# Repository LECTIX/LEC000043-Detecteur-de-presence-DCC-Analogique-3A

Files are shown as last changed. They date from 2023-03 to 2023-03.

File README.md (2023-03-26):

# LEC000043-Detecteur-de-presence-DCC-Analogique-3A
Fichiers sources pour le produit LEC000043

## Description du produit

### DCC (Digital)

En DCC, le détecteur d’occupation LEC000043 permet de détecter l’occupation d’un tronçon de voie et de déclencher de nombreux automatismes ou systèmes.
- Détecte tous les trains dans les **2 sens de marche**.
- Seuil de détection **réglable entre 1 et 10 mA**.
- **Courant max supporté** de 3A.
- Temporisation à la désactivation pour **éviter des réactivations intempestives**.
- **Possibilité de forcer** l'activation du relais via un bornier dédié.

### Analogique

Bien que ce module fonctionne en analogique de manière similaire au [LEC000042](https://github.com/LECTIX/LEC000042-Detecteur-de-presence-DCC-Analogique-1A), nous vous conseillons plutôt d'utiliser la version 1A pour une utilisation en analogique.

## Utiliser les fichiers sources pour fabriquer le produit

Il n'est **pas nécessaire de savoir souder ou d'être bon en électronique** pour se procurer ce produit. Grâce aux fichiers sources publiés ici, vous pouvez être en mesure de faire fabriquer ce produit par un sous traitant.

### Faire fabriquer chez un sous traitant

Il est aujourd'hui possible de faire fabriquer à moindre cout des cartes électroniques. Nous recommendons [JLCPCB](https://jlcpcb.com/) si vous voulez aller au moins cher. Si vous préférez un acteur européen, [eurocircuits](https://www.eurocircuits.com/) est un des acteurs reconnus.

IMAGE ALT TEXT (http://www.youtube.com/watch?v=RXGGvsUtz0c "TUTO : faire fabriquer un produit LECTIX")

1. Télécherger les sources de ce produit en cliquant sur le bouton `Code`, puis `Download ZIP`.
1. Décompresser le dossier.
1. Les fichiers pour la fabrication se trouvent dans le répertoire `hardware/prod`.
1. Se connecter sur [https://cart.jlcpcb.com/quote](https://cart.jlcpcb.com/quote)
1. Cliquer sur le bouton `Add gerber file` et sélectionner le fichier `gerbers.zip`.
1. Sélectionnez la quantité de cartes que vous souhaitez dans le champs `PCB Qty`.
1. Laisser toutes les autres options par défaut, puis cliquez sur le toggle switch en face de `PCB Assembly`, et enfin sur le bouton `confirm`.
1. Une preview de la carte électronique sans les composants doit apparaitre. Cliquez sur `NEXT`.
1. Cliquez sur le bouton `Add BOM File`, puis sélectionnez le fichier `bom.csv`
1. Cliquez sur le bouton `Add CPL File`, puis sélectionnez le fichier `pos.csv`
1. **Vérifier que tous les composants sont en stock** et bien sélectionnés, puis cliquez sur `NEXT`.
1. Une preview de la carte avec ses composants apparait. Continuer le chemin en cliquant sur `NEXT`.
1. Le prix final apparait. Sélectionnez la catégorie du produit, puis cliquez sur `SAVE TO CART`.
1. Une fois sauvegardé dans votre panier, vous pouvez valider votre commande et choisir le moyen d'acheminement. Afin de ne pas avoir à se préoccuper des frais de douane, nous vous conseillons de choisir une méthode d'expédition DDP.

Vous receverez vos cartes sous 1 à 3 semaines. 

**Nous ne sommes en aucun cas responsables des cartes qui arriveraient défectueuses ou non fonctionnelles.**

### Modifications des fichiers sources

Installez kicad 6 (ou version supérieure), et ouvrez le fichier LEC000043.kicad_pro

### Regénérer les fichiers gerber, BOM, et position (Optionnel)

Peut se faire simplement en utilisant kikit :

```
cd hardware
docker run --rm -w /kikit -v $PWD:/kikit yaqwsx/kikit kikit fab jlcpcb --assembly --no-drc --schematic LEC000043.kicad_sch --field LCSC --corrections JLCPCB_CORRECTION --nametemplate LEC000043_{} LEC000043.kicad_pcb prod/

```
## Notices

### DCC

[Manuel FR](docs/dcc/manual_fr.pdf)

[Manuel EN](docs/dcc/manual_en.pdf)

### Analogique

Se référer au produit [LEC000042](https://github.com/LECTIX/LEC000042-Detecteur-de-presence-DCC-Analogique-1A).

## License
Tous nos fichiers sont plubliés sous la license CERN Open Hardware Licence Version 2 - Strongly Reciprocal

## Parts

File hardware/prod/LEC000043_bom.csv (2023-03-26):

Comment | Designator | Footprint | LCSC
100uF | C1,C3 | 0_capacitors:CP_Elec_6.3x5.8 | C249982
100nF | C2,C5 | Capacitor_SMD:C_0603_1608Metric | C14663
10n | C6 | Capacitor_SMD:C_0603_1608Metric | C57112
10uF | C7,C8 | Capacitor_Tantalum_SMD:CP_EIA-3216-18_Kemet-A | C7171
MB10S | D1 | Package_TO_SOT_SMD:TO-269AA | C2488
1N4148WS | D2,D9,D10 | Diode_SMD:D_SOD-323 | C2128
RS3M | D3,D4,D5,D8 | Diode_SMD:D_SMC | C330389
D_Schottky_Small | D6 | Diode_SMD:D_SMA | C22452
LED | D7 | LED_SMD:LED_0603_1608Metric | C72043
FORCE_ACTIVATION | J1 | 0_connectors:TerminalBlock_bornier-2_P5.08mm-blue | C430621
TRACKS_OUT | J2 | 0_connectors:TerminalBlock_bornier-2_P5.08mm-blue | C430621
TRACKS_IN | J3 | 0_connectors:TerminalBlock_bornier-2_P5.08mm-green | C395849
CONTACT_1 | J5 | 0_connectors:TerminalBlock_bornier-3_P5.08mm-blue | C430620
CONTACT_2 | J6 | 0_connectors:TerminalBlock_bornier-3_P5.08mm-blue | C430620
HK19F-5V | K1 | 0_relays:Relay_DPDT_HK19F | C54512
47uH | L1 | Inductor_SMD:L_12x12mm_H6mm | C169398
S8050 | Q1 | Package_TO_SOT_SMD:SOT-23 | C2146
27 | R1 | Resistor_SMD:R_0603_1608Metric | C25190
3k | R2 | Resistor_SMD:R_0603_1608Metric | C4211
1k | R3,R5,R6 | Resistor_SMD:R_0603_1608Metric | C21190
180k | R4 | Resistor_SMD:R_0603_1608Metric | C22827
10k | R7 | Resistor_SMD:R_0603_1608Metric | C25804
500k | RV1 | 0_potentiometers:BOURNS-3362P_pot | C125021
NE555 | U1 | Package_SO:SOIC-8_3.9x4.9mm_P1.27mm | C7593
CYPC817 | U2 | Package_DIP:SMDIP-4_W9.53mm_Clearance8mm | C385060
XL1509-ADJE1 | U3 | Package_SO:SOP-8_3.76x4.96mm_P1.27mm | C74192

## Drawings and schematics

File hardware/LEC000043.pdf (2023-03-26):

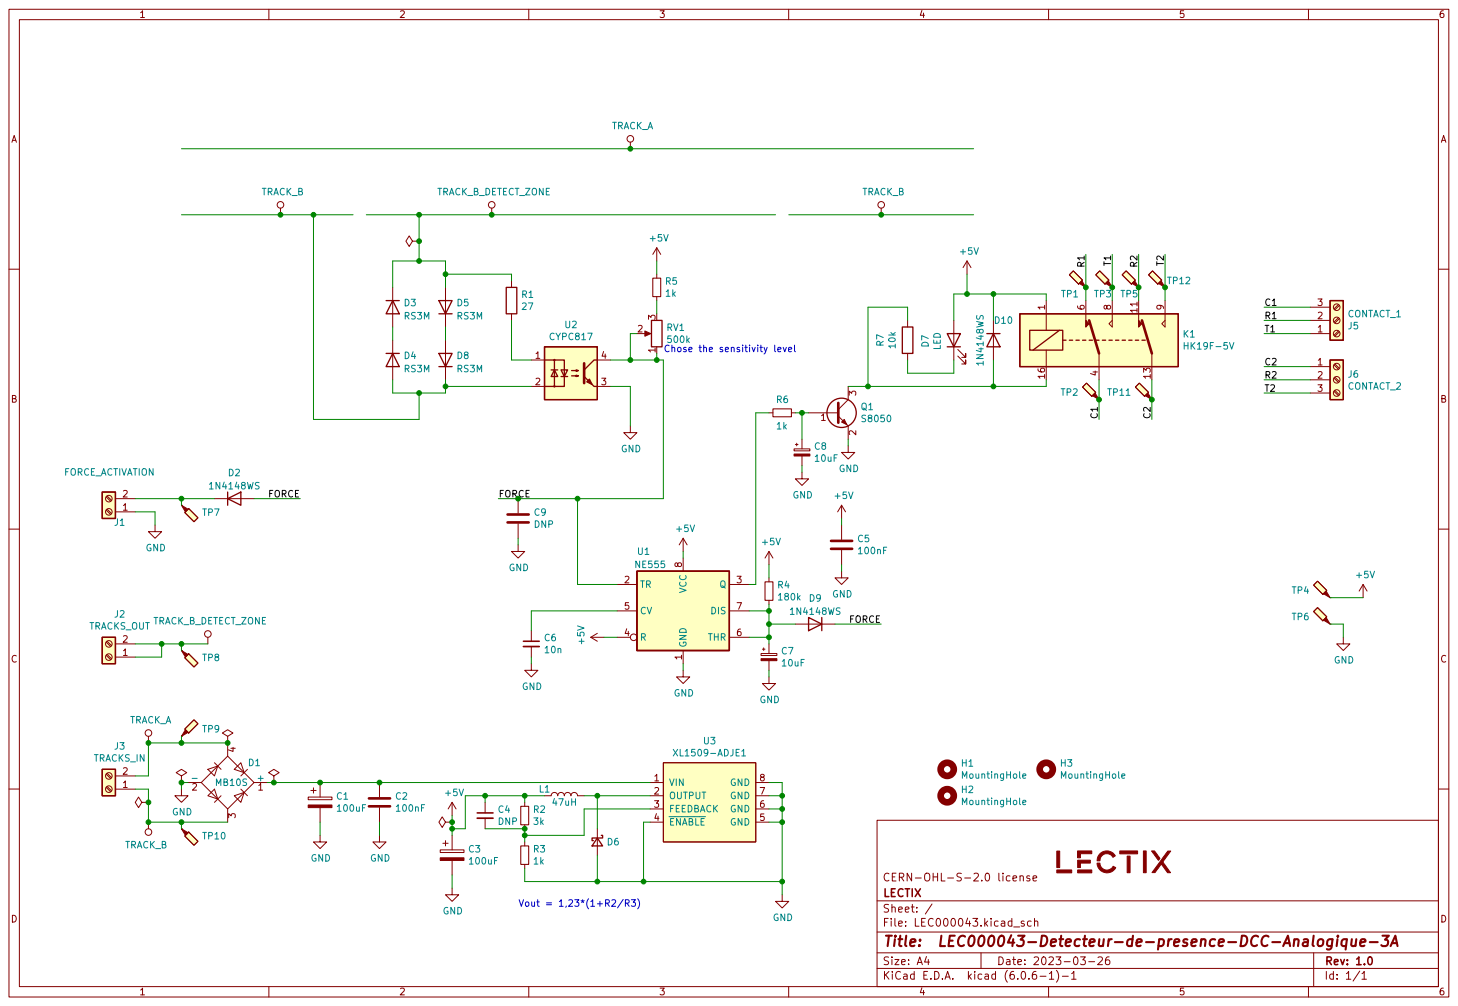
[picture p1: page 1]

File: LEC000043.kicad_sch Sheet: / LECTIX CERN-OHL-S-2.0 license

Id: 1/1 Title: LEC000043-Detecteur-de-presence-DCC-Analogique-3A

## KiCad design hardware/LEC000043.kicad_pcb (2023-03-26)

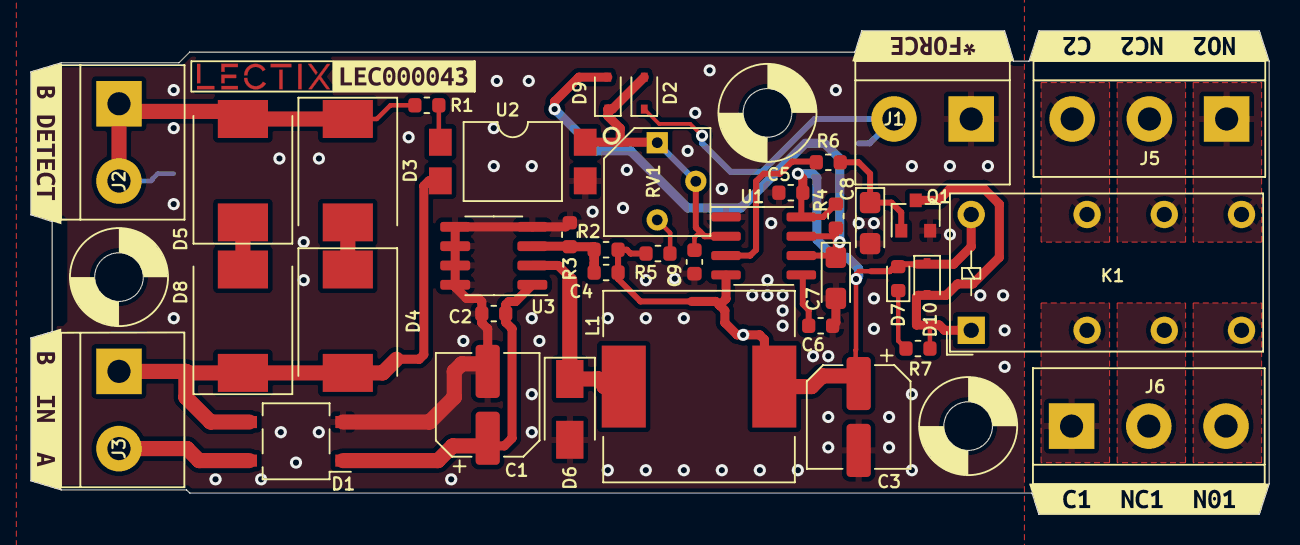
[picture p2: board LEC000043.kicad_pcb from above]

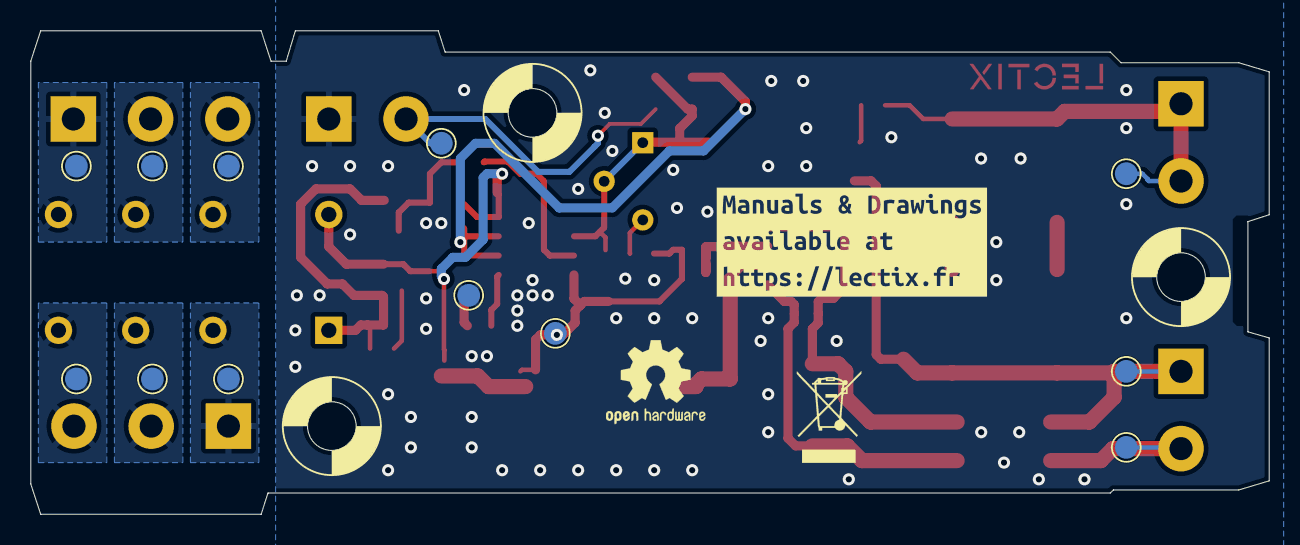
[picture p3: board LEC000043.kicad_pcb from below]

Board: 2 copper layers, 81.4 x 31.8 mm, 61 parts (13 on the bottom side), 26 nets.

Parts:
C1, C3: 100uF; CP_Elec_6.3x5.8
C2, C5: 100nF; C_0603_1608Metric
C4, C9: DNP; C_0603_1608Metric
C6: 10n; C_0603_1608Metric
C7, C8: 10uF; CP_EIA-3216-18_Kemet-A
D1: MB10S; TO-269AA
D2, D9, D10: 1N4148WS; D_SOD-323
D3, D4, D5, D8: RS3M; D_SMC
D6: D_Schottky_Small; D_SMA
D7: LED; LED_0603_1608Metric
H1, H2, H3: MountingHole; MountingHole_3.2mm_M3
J1: FORCE_ACTIVATION; TerminalBlock_bornier-2_P5.08mm-blue
J2: TRACKS_OUT; TerminalBlock_bornier-2_P5.08mm-blue
J3: TRACKS_IN; TerminalBlock_bornier-2_P5.08mm-green
J5: CONTACT_1; TerminalBlock_bornier-3_P5.08mm-blue
J6: CONTACT_2; TerminalBlock_bornier-3_P5.08mm-blue
K1: HK19F-5V; Relay_DPDT_HK19F
L1: 47uH; L_12x12mm_H6mm
LOGO1: logo_lectix_25mm; Logo_10mm
Q1: S8050; SOT-23
R1: 27; R_0603_1608Metric
R2: 3k; R_0603_1608Metric
R3, R5, R6: 1k; R_0603_1608Metric
R4: 180k; R_0603_1608Metric
R7: 10k; R_0603_1608Metric
RV1: 500k; BOURNS-3362P_pot
TP1, TP2, TP3, TP4, TP5, TP6, TP7, TP8, TP9, TP10, TP11, TP12: TestPoint_Probe; TestPoint_Pad_D1.5mm
U1: NE555; SOIC-8_3.9x4.9mm_P1.27mm
U2: CYPC817; SMDIP-4_W9.53mm_Clearance8mm
U3: XL1509-ADJE1; SOP-8_3.76x4.96mm_P1.27mm
kibuzzard-624D4A7D: G***; kibuzzard-624D4A7D
kibuzzard-624D4ACF: G***; kibuzzard-624D4ACF
kibuzzard-624D4AF8: G***; kibuzzard-624D4AF8
kibuzzard-624D4BCC: G***; kibuzzard-624D4BCC
kibuzzard-624D4BDE: G***; kibuzzard-624D4BDE
kibuzzard-624D5053: G***; kibuzzard-624D5053
kibuzzard-627C05F6: G***; kibuzzard-627C05F6

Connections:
+5V: C3.1, C4.1, C5.1, D7.2 (A), D10.1 (K), K1.1, L1.1, R2.1, R4.1, R5.1, TP4.1, U1.4 (R), U1.8 (VCC)
/C1: J5.3, K1.4, TP2.1
/C2: J6.1, K1.13, TP11.1
/FORCE: C9.1, D2.2 (A), D9.1 (K), RV1.1, RV1.2, U1.2 (TR), U2.4
/R1: J5.2, K1.6, TP1.1
/R2: J6.2, K1.11, TP5.1
/T1: J5.1, K1.8, TP3.1
/T2: J6.3, K1.9, TP12.1
GND: C1.2, C2.2, C3.2, C5.2, C6.2, C7.2, C8.2, C9.2, D1.2 (-), D6.2 (A), J1.1, Q1.2 (E), R3.2, TP6.1, U1.1 (GND), U2.3, U3.4 (~ENABLE), U3.5 (GND), U3.6 (GND), U3.7 (GND), U3.8 (GND)
unnamed: C1.1, C2.1, D1.1 (+), U3.1 (VIN)
unnamed: C4.2, R2.2, R3.1, U3.3 (FEEDBACK)
unnamed: C6.1, U1.5 (CV)
unnamed: C7.1, D9.2 (A), R4.2, U1.6 (THR), U1.7 (DIS)
unnamed: C8.1, Q1.1 (B), R6.1
unnamed: D3.2 (A), D4.1 (K)
unnamed: D5.1 (K), D8.2 (A)
unnamed: D6.1 (K), L1.2, U3.2 (OUTPUT)
unnamed: D7.1 (K), R7.2
unnamed: D10.2 (A), K1.16, Q1.3 (C), R7.1
unnamed: D2.1 (K), J1.2, TP7.1
unnamed: R1.2, U2.1
unnamed: R5.2, RV1.3
unnamed: R6.2, U1.3 (Q)
TRACK_A: D1.4, J3.2, TP9.1
TRACK_B: D1.3, D4.2 (A), D8.1 (K), J3.1, TP10.1, U2.2
TRACK_B_DETECT_ZONE: D3.1 (K), D5.2 (A), J2.1, J2.2, R1.1, TP8.1

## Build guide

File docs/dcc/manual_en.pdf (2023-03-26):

# 3A Occupancy detector (DCC)

### LEC000043

☞ Warning: this manual describes the use of the module LEC000043 for an installation in digital only. For analog use, go to our website. (https://lectix.fr/?lang=en)

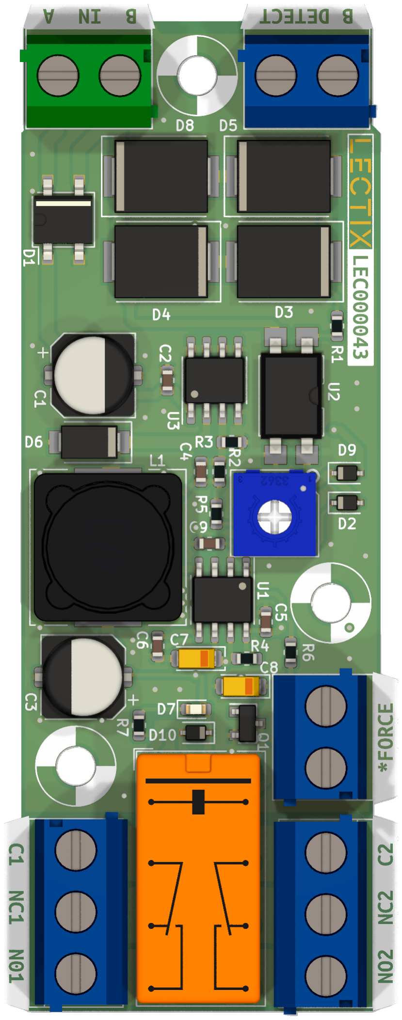
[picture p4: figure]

## 1 Overview

- Able to detect all trains in both directions, even when stationary.
- Possible adjustment of the detection threshold (from 1 mA to 10 mA).
- Has a relay with 2 independent changeover contacts.
- Activation indicator light.
- Possibility to force the activation of the module.
- Delay on deactivation to avoid unwanted reactivations.
- 3 screw holes for easy mounting.

## 2 Applications

- Block system.
- Triggering a sound eect.
- Hidden station management.
- Automatisms (level crossing, ...)..
- Signage management.

## 3 Technical specifications

Specification | Value | Unit
Threshold of detection | 1 - 10 | mA
Consumption (inactif @20V) (actif @20V) | 3.5 17 | mA mA
Relay breaking capacity | 1A 125V AC 2A 30V DC | -
Maximum supported current | 3 | A

Table 1: Specifications

LEC000043 - 3A Occupancy detector (DCC) rev 4.2.3 | 1

## 4 Usage

In DCC, the occupancy detector LEC000043 allows to detect the occupation of a section of track and to trigger numerous automatisms or systems. The adjustable sensitivity of the module will allow you to detect without any worries your locomotives, cars with lighting, or even the end of train lights of your rolling stock.

### 4.1 Installation and wiring of the module

☞ Remark: for optimal and safe operation, the wiring of this module must be done with a wire having a minimum section of 0.2mm²

The module must be wired as shown in the figure 1. Note that it is important to respect the association of a rail with a leer (A or B).

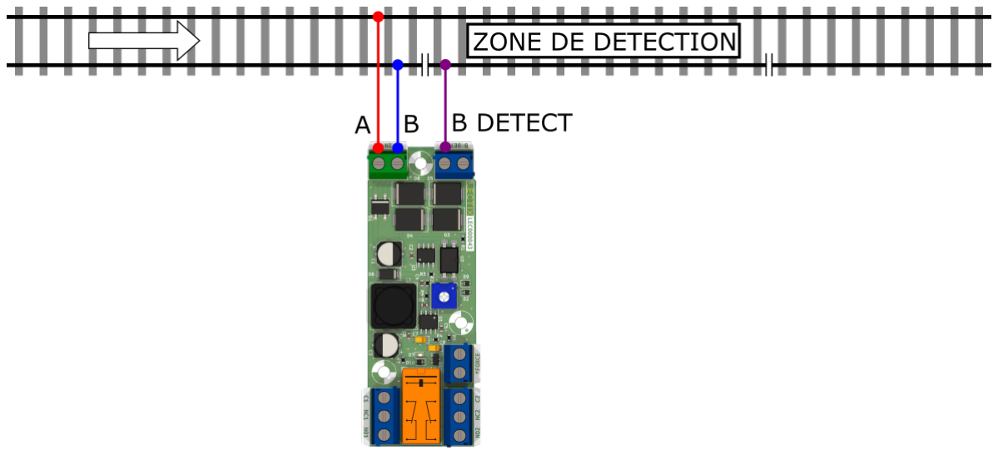
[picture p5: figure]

Figure 1: Module wiring diagram.

For a quick and easy installation:

1. Isolate one of the rails in your detection area.
2. Connect the power supply rails, or directly the wires coming from the DCC central unit to the green terminal block (terminals A and B).
3. Connect the insulated rail to one of the 2 B DETECT terminal.
4. Test and take advantage of all the possibilities oered by the detector’s changeover contacts.
5. Fix the module with screws or hot glue.

Once the connections of the figure 1 made, you can connect a system or an automation to be activated thanks to the relay’s changeover contacts (See. figure 2). You will find examples of use at the end of this manual.

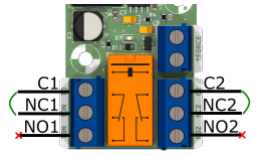
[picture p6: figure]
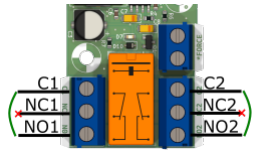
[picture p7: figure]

(a) Relay deactivated. | (b) Relay activated.

Figure 2: Description of the relay’s changeover contacts.

4.2 (optional) Forcing the activation of the relay.

Some systems, such as station stop management, may require the need to force relay activation. To do this, simply connect the two FORCE terminals with a switch (See. figure 3).

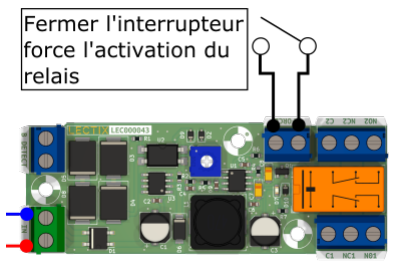
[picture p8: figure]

Figure 3: Forcing the activation of the relay.

4.3 (optional) Adjust the sensitivity of the detection.

The module comes pre-set to a standard detection sensitivity that should allow detection of any locomotive, even when stationary (detection of the machine’s decoder consumption). If you are not satisfied with the detection level, you can adjust it as shown in the figure 4.

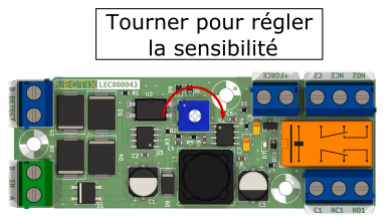
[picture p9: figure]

Figure 4: Seing the detection threshold.

To decrease the sensitivity, turn the potentiometer clockwise.
To increase the sensitivity, turn the potentiometer counter-clockwise.

☞ Note : The potentiometer is very fragile. Never force it to deteriorate or make the module inoperable.

### 4.4 Examples of use

The relay’s contacts present on the module allow a very generic use. Here are some examples of use.

4.4.1 Connection of a two-tone light.

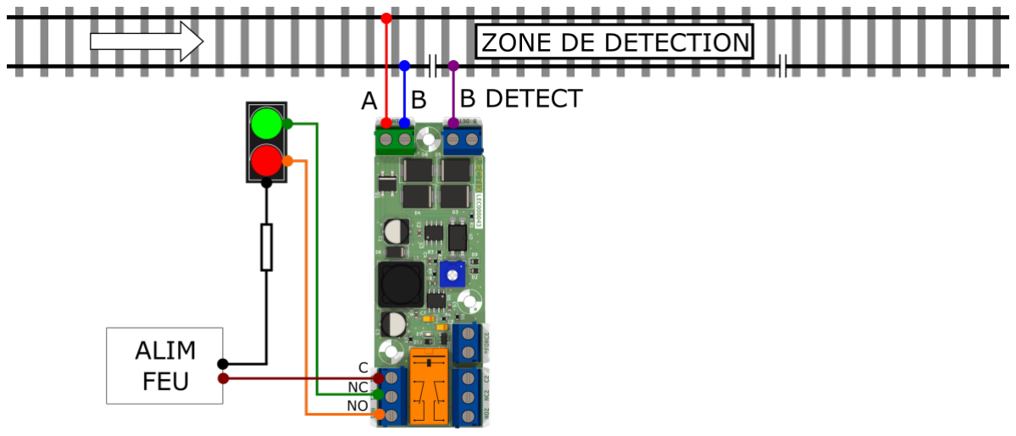
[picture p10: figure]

Figure 5: Connection of a two-tone light.

### 4.4.2 Triggering of a sound signal (horn, ...)

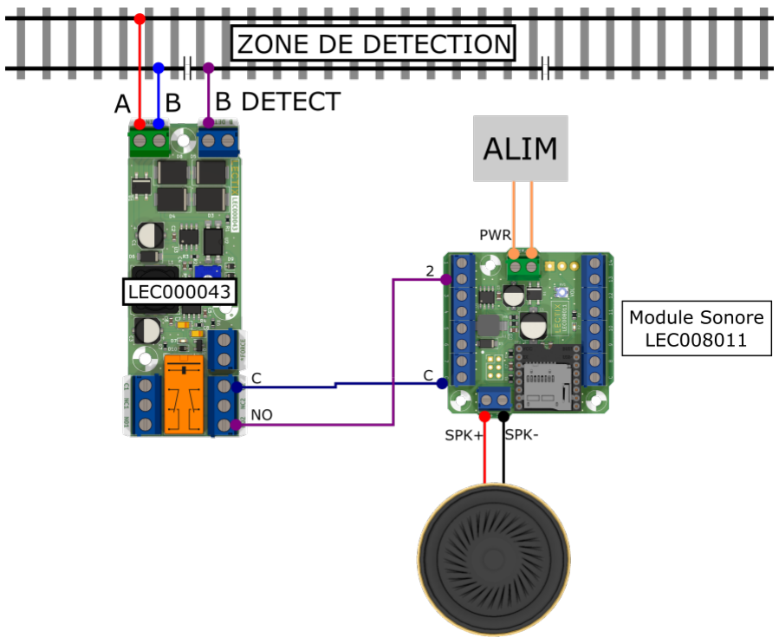
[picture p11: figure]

Figure 6: Triggering a sound signal.

4.4.3 Section protection with automatic stop.

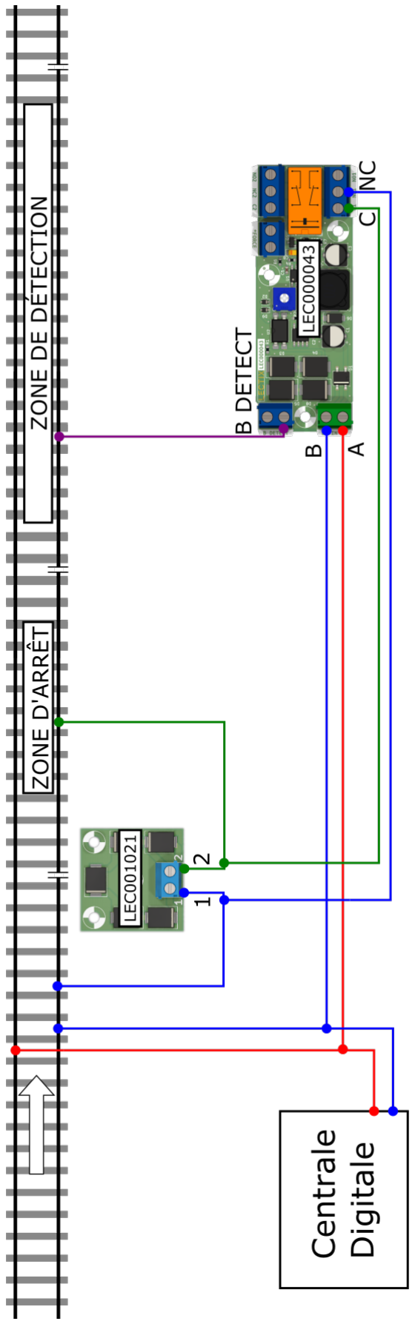
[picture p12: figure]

Figure 7: Section protection with automatic stop.

4.4.4 Single block with stop module LEC001020.

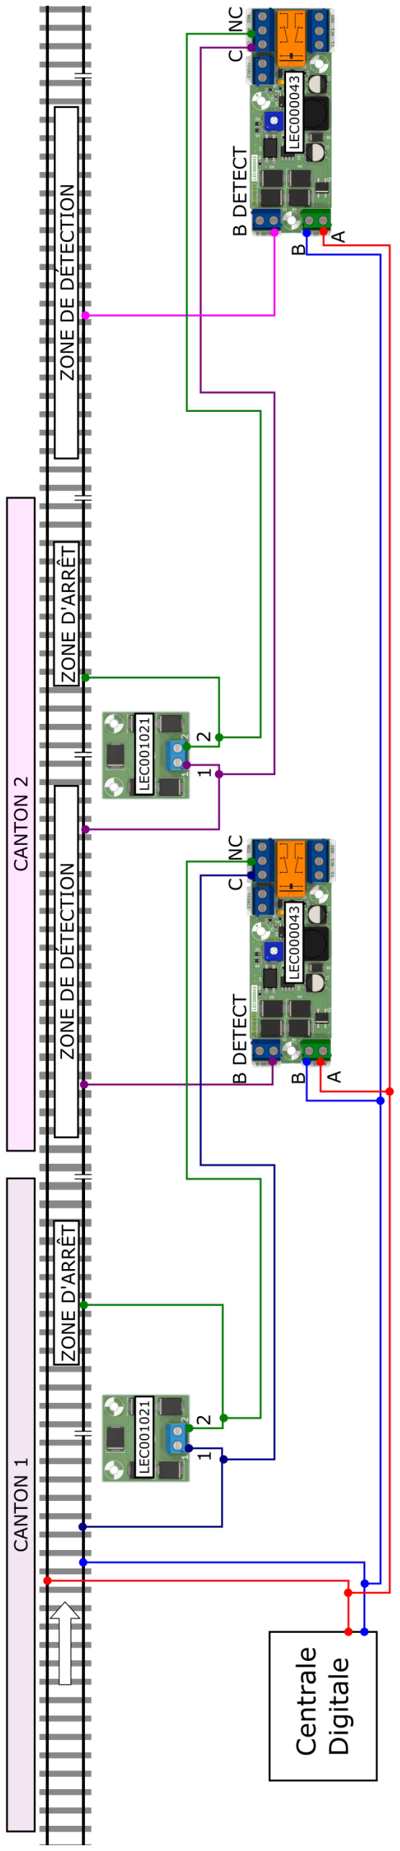
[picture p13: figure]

Figure 8: Single block with stop module LEC001020.

4.4.5 Addition of a two-tone light in a block-type installation.

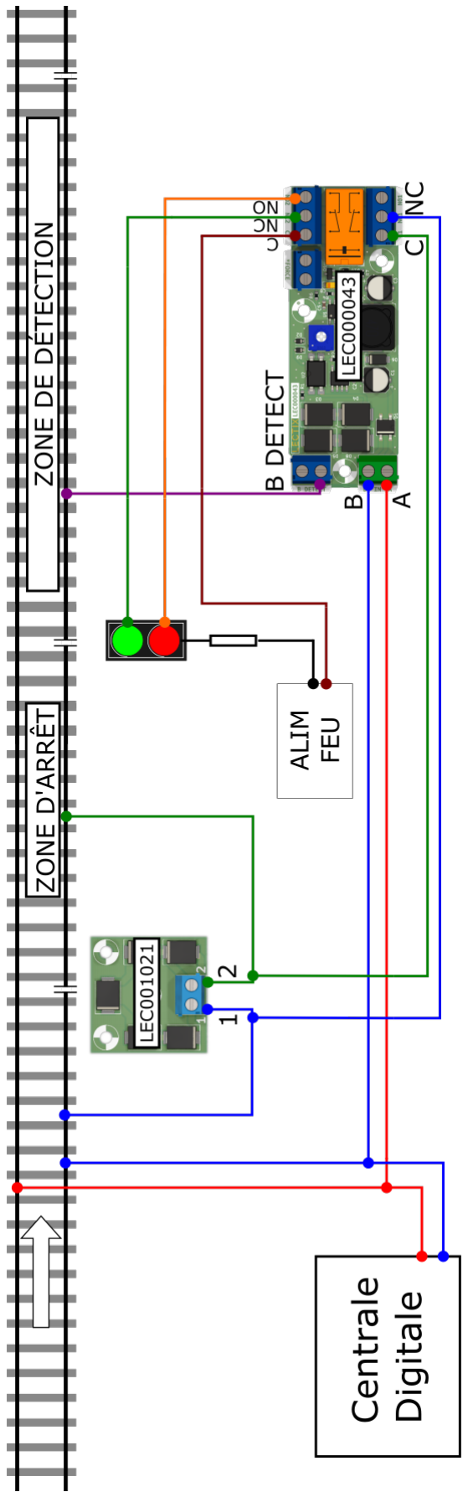
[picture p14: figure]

Figure 9: Addition of a two-tone light in a block-type installation.

4.4.6 Manage a switch in a detection zone.

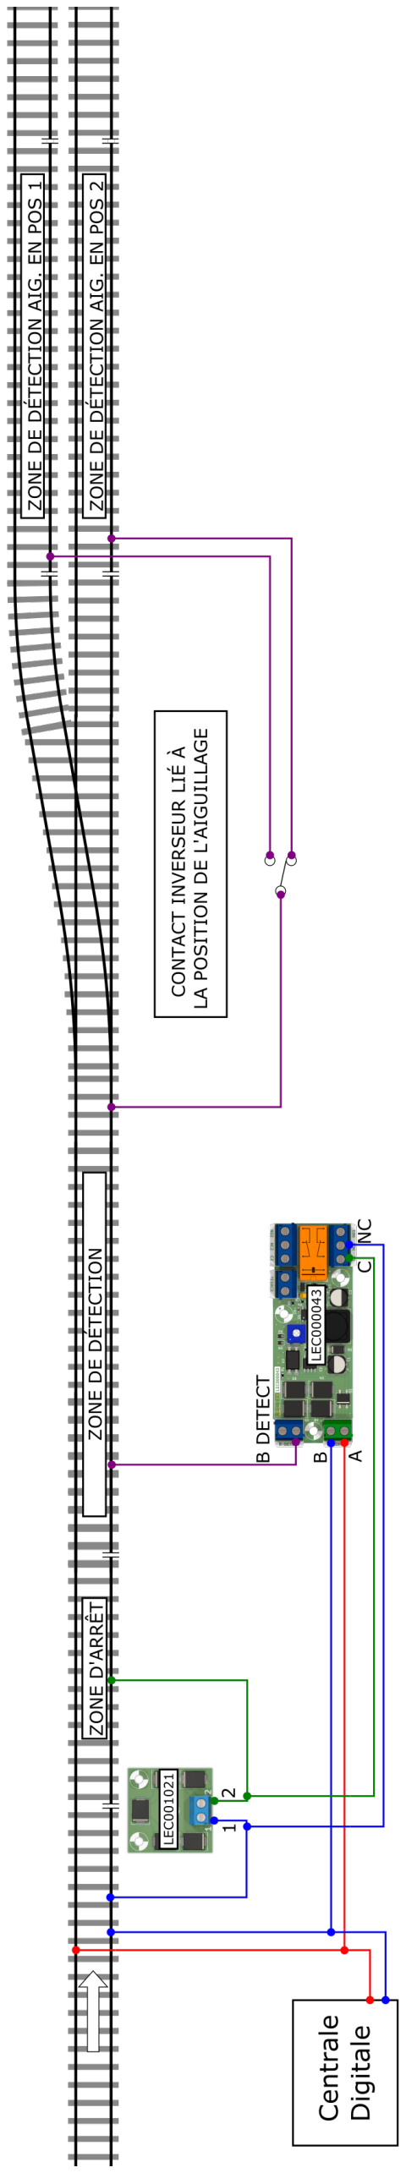
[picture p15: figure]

Figure 10: Manage a switch in a detection zone.

4.4.7 Managing a switch at the end of a siding.

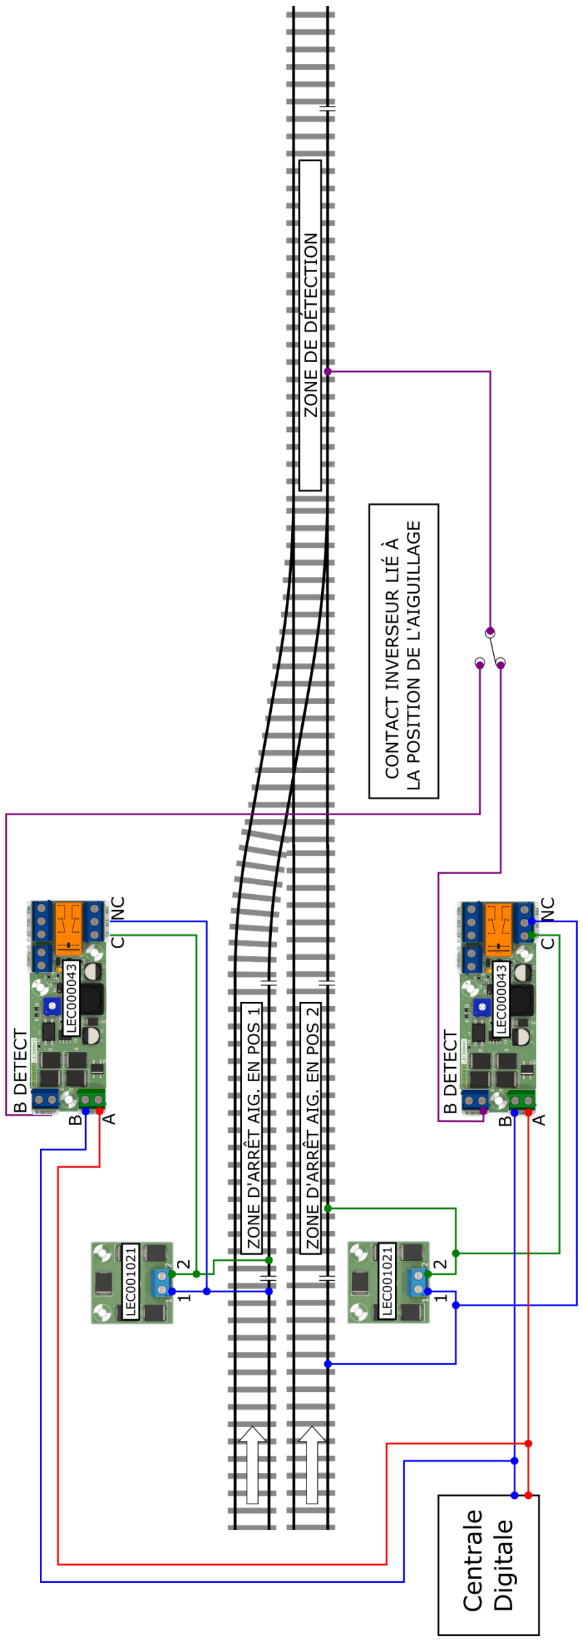
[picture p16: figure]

Figure 11: Managing a switch at the end of a siding.

4.4.8 Successive blocks with stop module LEC001020.

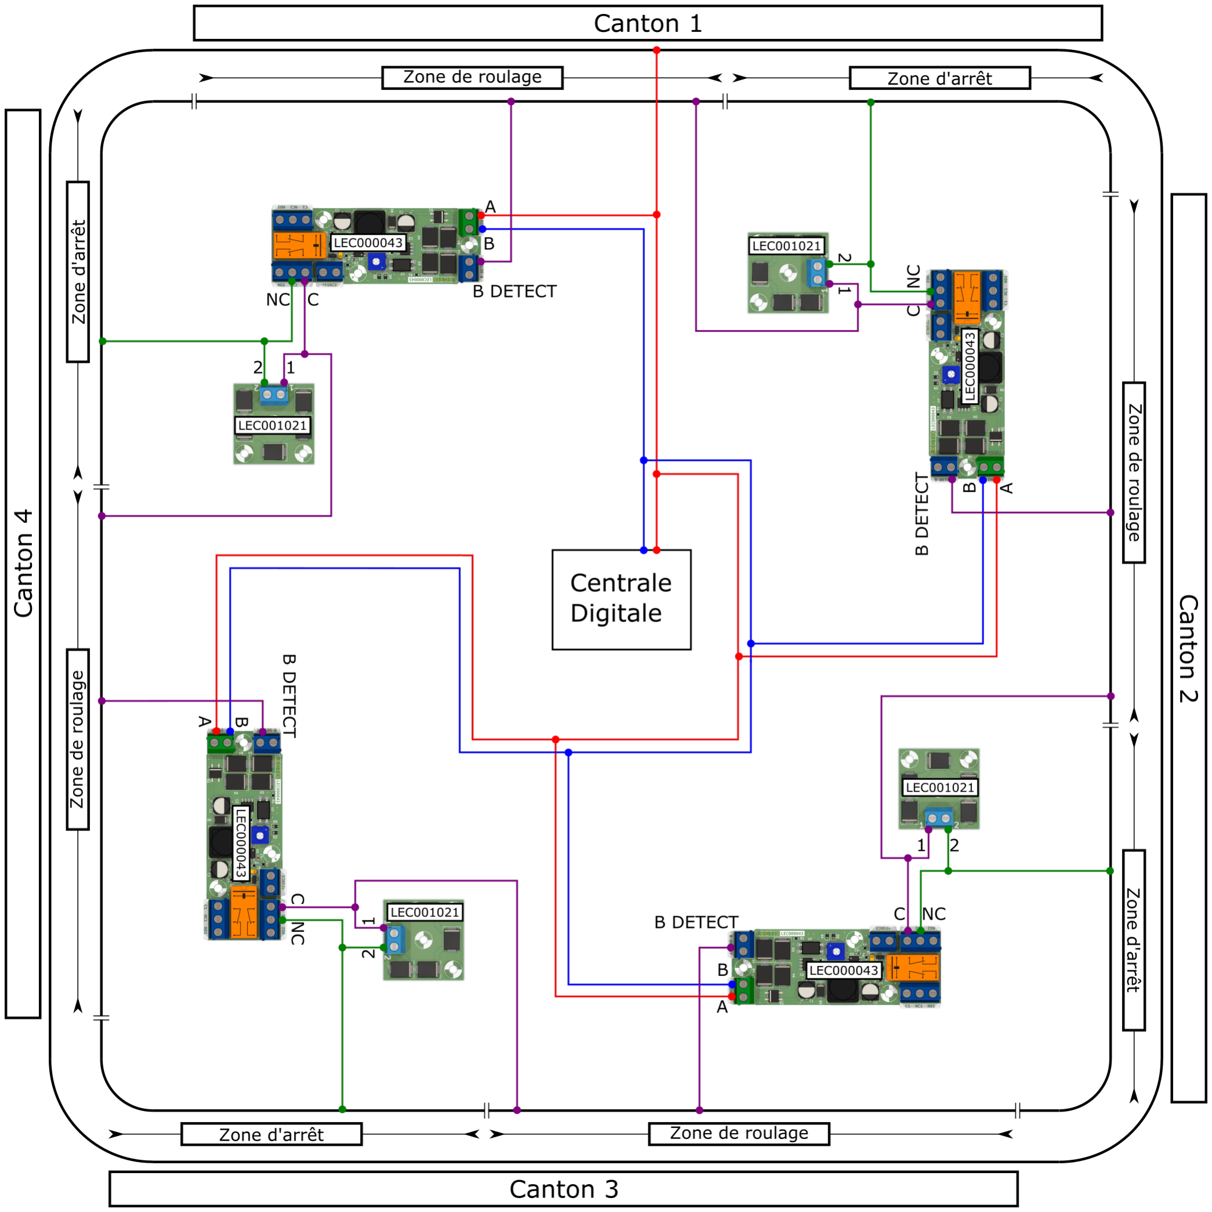
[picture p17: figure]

Figure 12: Successive blocks systems.

4.4.9 Successive blocks with stop module LEC001020 without rolling zones.

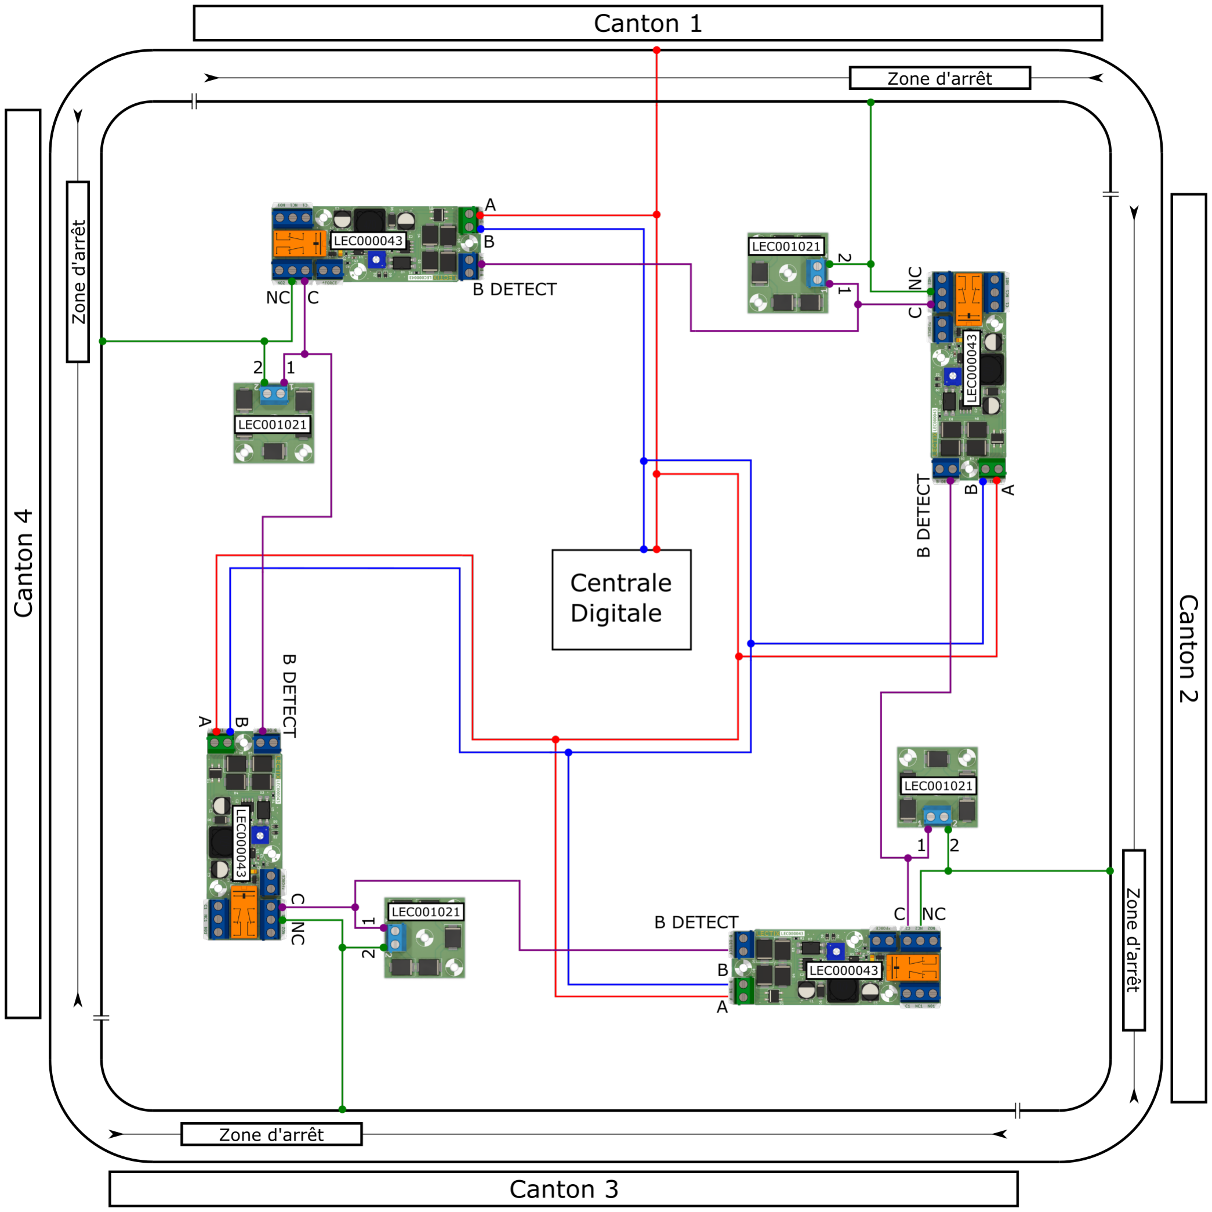
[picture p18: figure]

Figure 13: Chain of block systems without rolling zones.

## 5 Contact and support

For further information, please contact contact@lectix.fr.

## Revision History

Revision Date | Author(s) | Description
4.2.0 | 11.12.21 TFC | Adaptation of the manual from LEC000041
4.2.1 | 22.03.22 TFC | Updated Figure 9 to move townships to correct lo-
cations.
4.2.2 | 17.04.22 TFC | Updating the manual to provide translations.
4.2.3 | 17.06.22 TFC | Adaptation of the manual from LEC000042.

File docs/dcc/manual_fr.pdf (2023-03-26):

# Détecteur d’occupation 3A (DCC)

### LEC000043

☞ Aention : ce manuel décrit l’utilisation du module LEC000043 pour une installation en digital uniquement. Pour une utilisation en analogique, rendez vous sur notre site web. (https://lectix.fr/)


## 1 Caractéristiques

- Capable de détecter tous les trains dans les 2 sens de marche, même à l’arrêt.
- Réglage possible du seuil de détection (de 1 mA à 10 mA).
- Possède un relais à 2 contacts inverseurs indépendants.
- Témoin lumineux d’activation.
- Possibilité de forcer l’activation du module.
- Temporisation à la désactivation pour éviter des réactivations intempestives.
- 3 trous de fixation pour un montage facile.

## 2 Applications

- Cantonnement.
- Déclenchement d’un bruitage.
- Gestion de gares cachée.
- Automatismes (passage à niveau, ...).
- Gestion de la signalisation.

## 3 Specifications technique

Specification | Valeur | Unité
Seuil de détection | 1 - 10 | mA
Consommation (inactif @20V) (actif @20V) | 3.5 17 | mA mA
Pouvoir de coupure du relais | 1A 125V AC 2A 30V DC | -
Courant max supporté | 3 | A

Table 1: Spécifications

LEC000043 - Détecteur d’occupation 3A (DCC) rev 4.2.3 | 1

## 4 Utilisation

En DCC, le détecteur d’occupation LEC000043 permet de détecter l’occupation d’un tronçon de voie et de déclencher de nombreux automatismes ou systèmes. La sensibilité réglable du module vous permera de détecter sans aucun soucis vos locomotives, wagons ayant de l’éclairage, ou encore les feux de fin de convois de votre matériel roulant.

### 4.1 Installation et câblage du module

☞ Remarque : pour un fonctionnement optimal et sans danger, le câblage de ce module doit se faire avec un fil possédant une section minimale de 0.2mm²

Le module doit être câblé tel que sur la figure 1. A noter qu’il est important de respecter l’association d’un rail à une lere (A ou B).


Figure 1: Schéma de câblage du module.

L’installation du système est simple et rapide :

1. Isolez un des rail de votre zone de détection.
2. Branchez les rails d’alimentation, ou directement des fils provenant de la centrale DCC sur le bornier vert (bornes A et B).
3. Branchez le rail isolé sur une des 2 bornes B DETECT.
4. Testez et profitez de toutes les possibilités oertes par les contacts inverseurs du détecteur.
5. Fixez le module à l’aide de vis ou de colle chaude.

Une fois les branchements de la figure 1 eectués, vous pouvez brancher un système ou un automatisme à activer grâce aux contacts inverseurs du relais (Cf. figure 2). Vous trouverez des exemples d’utilisation à la fin de ce manuel.

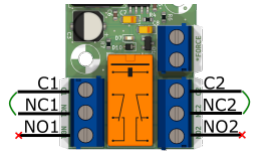
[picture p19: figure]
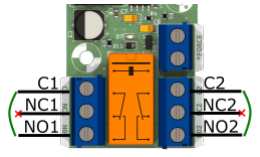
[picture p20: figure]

(a) Relais désactivé. | (b) Relais activé.

Figure 2: Description des contacts inverseurs du relais.

4.2 (optionnel) Forcer l’activation du relais.

Certains systèmes, tels que la gestion d’un arrêt en gare, peuvent nécessiter le besoin de forcer l’activation du relais. Pour ce faire, il vous suira de relier les deux bornes FORCE par un interrupteur (Cf. figure 3).


Figure 3: Forçage de l’activation du relais.

4.3 (optionnel) Régler la sensibilité de la détection.

Le module arrive pré-réglé sur une sensibilité de détection standard qui devrait permere de détecter toute locomotive, même à l’arrêt (détection de la consommation du décodeur de la machine). Si jamais le niveau de détection ne vous satisfait pas, il est possible de le régler comme indiqué sur la figure 4.


Figure 4: Réglage du seuil de détection.

Pour diminuer la sensibilité, tourner le potentiomètre dans le sens des aiguilles d’une montre. Pour augmenter la sensibilité, tourner le potentiomètre dans le sens inverse des aiguilles d’une montre.

☞ Note : Le potentiomètre est très fragile. NE jamais forcer dessus pour ne pas détériorer ou rendre inopérable le module.

### 4.4 Exemples d’utilisation

Les contacts inverseur du relais du module permeent une utilisation très générique. Voici quelques exemples d’utilisation.

4.4.1 Branchement d’un feu bicolore.


Figure 5: Branchement d’un feu bicolore.

### 4.4.2 Déclenchement d’un signal sonore (Klaxon, ...)


Figure 6: Déclenchement d’un signal sonore.

4.4.3 Protection d’un tronçon avec arrêt automatique.


Figure 7: Protection d’un tronçon avec arrêt automatique.

4.4.4 Canton simple avec module d’arrêt LEC001020.


Figure 8: Canton simple avec module d’arrêt LEC001020.

4.4.5 Ajout d’un feu bicolore dans un montage de type cantonnement.


Figure 9: Ajout d’un feu bicolore dans un montage de type cantonnement.

4.4.6 Gérer un aiguillage dans une zone de détection.


Figure 10: Gérer un aiguillage dans une zone de détection.

4.4.7 Gérer un aiguillage en fin de voie d’évitement.


Figure 11: Gérer un aiguillage en fin de voie d’évitement.

4.4.8 Cantons successifs avec module d’arrêt LEC001020.

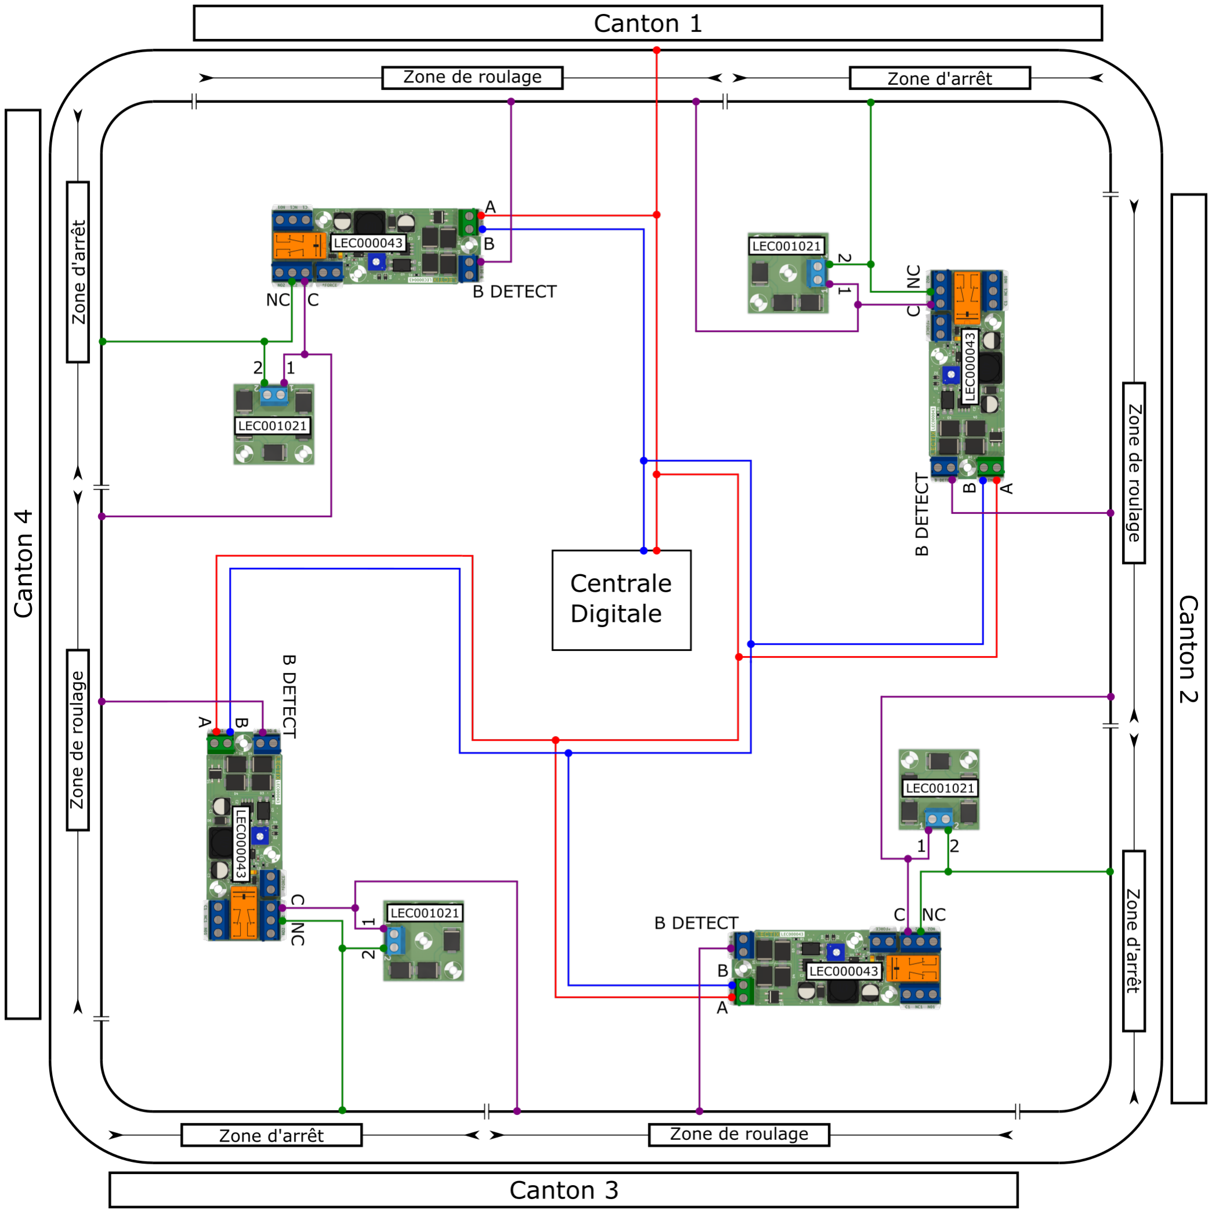
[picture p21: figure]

Figure 12: Cantons successifs.

4.4.9 Cantons successifs avec module d’arrêt LEC001020 sans zones de roulage.


Figure 13: Cantons successifs sans zones de roulage.

## 5 Contact et SAV

Pour tout renseignement, veuillez vous adresser à contact@lectix.fr.

## Revision History

Revision Date | Author(s) | Description
4.2.0 | 11.12.21 TFC | Adaptation du manuel depuis LEC000041
4.2.1 | 22.03.22 TFC | Mise à jour de la figure 9 pour replacer les cantons
aux bons endroits.
4.2.2 | 17.04.22 TFC | Mise à jour du manuel pour proposer des traduc-
tions.
4.2.3 | 17.06.22 TFC | Adaptation du manuel depuis LEC000042.

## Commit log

2023-03-26 Add source files
    [LEC000043.kicad_pcb, LEC000043.kicad_sch]
2023-03-26 Add prod files
    [LEC000043-CmtUser.gbr, LEC000043-CuBottom.gbl, LEC000043-CuTop.gtl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]
2023-03-26 Add pdf schematic file
